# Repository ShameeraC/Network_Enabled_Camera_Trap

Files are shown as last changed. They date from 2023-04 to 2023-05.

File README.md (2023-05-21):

# Network-Enabled Camera Trap
This project deals with improving existing research equipment for ornithologists. One of the major concerns faced by researchers studying red-winged starlings at the University of Cape Town and its surrounding area, is that they are lacking the necessary funds and manpower to monitor their feeding and nesting behaviour. To address this issue, our team has decided to design a network-enabled camera trap.

The camera trap uses a PIR sensor to trigger a photo being taken. The photo is then saved to an  SD card, along with environmental data such as temperature and humidity measured by the camera trap's sensor. Afterwards, the camera trap uploads the saved image to Google Drive as well.

This repository details the design, testing, documentation and implementation of a network-enabled camera trap aimed at solving these problems completed by [Shameera Cassim](https://github.com/ShameeraC), [Thato Khoabane](https://github.com/kingtysen1969), [Litha Nohashe](https://github.com/lithanohasheUCT) and [Stefan Friedrich](https://github.com/stefanfriedric).

## File Structure
### Subsystems
This folder includes 4 subfolders - one for each submodule in the system. These are:
 * Camera System
    * By Stefan Friedrich
 * Image Transmission and Processing
    * By Shameera Cassim
 * Mounting and Housing
    * By Litha Nohashe
 * Power Management
    * By Thato Khaboane

### Documentation
Contains all relevant documentation for the project including project submissions.

### Interfacing
Contains all files relating to two or more subomdules.

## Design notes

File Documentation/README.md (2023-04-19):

# Network-Enabled Camera Trap/Documentation
Contains all relevant documentation for the project including project submissions.

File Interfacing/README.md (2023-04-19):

# Network-Enabled Camera Trap/Interfacing
Contains all files relating to two or more subomdules.

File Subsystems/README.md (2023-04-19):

# Network-Enabled Camera Trap/Subsystems
This folder includes 4 subfolders - one for each submodule in the system. These are:
Camera System;
Communication;
Mounting and Housing; and
Power Management.

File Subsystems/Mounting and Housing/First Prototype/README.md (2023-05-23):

This folder contains the design of the first prototype.

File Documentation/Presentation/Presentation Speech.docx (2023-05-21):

Intro & Problem Statement:

INTERESTING INTRO LINE

Good afternoon Dr. Paine, Dr. Schonken and the rest of the audience. Monitoring animals by hand is a long and tedious process. It often involves setting up camp in one spot with a hand-held camera and a notebook for several hours at a time. While nothing quite beats the thrill of capturing good data, a researcher’s presence in an animal’s habitat could disturb them or drive them away. Some animals, like birds, also build their nests in trees or on top of high buildings. This poses problems for the observer. An easy solution is obviously using a camera trap.

CLICK

The inspiration for this project comes from Dr Celiwe Ngcamphalala who studies red-winged starlings on UCT Upper Campus. Her research forms a part of the global change and urban birds research project at the FitzPatrick Institute. Red-Winged Starlings are known for thriving on UCTs campus, and the behaviour of these birds is studied by several ornithologists. Dr Ngcamphalala needs a low-cost solution for tracking the activity of red-winged starlings in their nests. This includes, among other things, how long it takes for their eggs to hatch and the birds’ feeding behavior.

In response, we have developed a low-cost network-enabled camera trap to be used by ornithologists at the FitzPatrick Institute. The final system is triggered by body heat and takes photos which are uploaded to Google Drive with environmental sensor data. These images are processed at a later stage.

CLICK

Housing:

Following the project taking a life of its own, resulting in a shift in focus, this system had to be adapted from a wild, remote outdoor area to a more urban and furnished environment. The assembly is made of two parts; one to house the camera and transmission circuitry, and one to house the power supplying system. The housing opens only to expose the sensors to the environment during operation, otherwise it is built enclosed.

Due to the narrow nature of the setting environment, the circuit boards and the housing were optimized to be compact in terms of size, but to also leave some space for mounting. It is recommended that the system be mounted with a variation of a chair angle bracket where it should rest on its longest side (resulting in a setting whereby it is longer horizontally). Because of its lightweight nature and simplicity, there is a lot of flexibility around how this may be achieved. This is ideal given that these birds build their nests in the most random places on campus. For ease of use, cable ties may be used to keep the system in place with respect to the bracket or alternatively, they may be joined using bolts, nuts and washers.

CLICK

Power:

The power subsystem has

CLICK

Camera:

The camera subsystem has both hardware and software components. Put together, it is able to capture a photo of an animal as it passes by. Not only does it do this, but it also captures environmental data such as temperature and humidity. The picture taken is then stored on an SD card, along with the environmental data, which is embedded in the image name.

To achieve this functionality, the ESP32-CAM was used. It is a low-cost microcontroller which features an on-board 2MP camera. It also consumes little power, especially in deep-sleep mode, making it ideal for longer deployments. An external trigger was used to wake the camera up and let it know that an animal is passing by. This trigger took the form of a Passive Infra-Red (PIR) sensor circuit, which registers a difference between the ambient temperature and the body heat of an animal.

The prototype circuit was built and tested. Overall, the picture quality is satisfactory, but the camera does sometimes take photos that have a greenish hue. This usually happens during the initialization of the camera and therefore only affects the first couple of photos. It could be prevented by increasing the shutter delay, but this comes at the risk of missed images. Otherwise, the PIR sensor works well up to 7m away from a target. Naturally, some false triggering still occurs but future iterations of the camera subsystem could include on-board image processing to remove these false triggers from the picture batch. As of right now, however, this is left to a separate submodule.

CLICK

Image Transmission and Processing:

The Image Transmission and Processing subsystem has two main functions. It uploads the images taken by the camera subsystem to a Google Drive folder and processes the files to extract relevant data. The purpose of this is to allow for real-time access to data and reduce demand on researchers to manually sort through captured data thus saving time and effort that could be better spent elsewhere.

The transmission part of this subsystem is executed using the ESP-32 microcontroller and 2 main software components. The onboard code connects the camera to the internet and uploads images to Google Drive. Currently the board connects to a mobile hotspot. Further development would include connecting to eduroam (as research is on campus) or adding an additional wifi access point so that a mobile hotspot is not needed.

The image processing part of the subsystem does 2 main things:

- It checks if there is a bird in each image and stores a list of the images that do contain birds; and
- It processes this list of file names which contain temperature, humidity, and heat index data from the camera subsystem.

The images and graphs shown on the slide above are generated by the image processing subsystem which circles what it recognizes as a bird and plots the relevant data. Due to time constraints, the images were not taken with the system but rather with a cell phone.

This is all done in a Google Colab notebook allowing for easy access to the Google Drive. This also means that no images need to be downloaded before processing. Only images containing birds are processed and the data retrieved is plotted. Future development would include a dashboard with access to the images that do have birds in them as well as plots and further analysis of the data. A better object detection model would also be developed to ensure that no photos are incorrectly excluded from processing and to identify whether a bird is a starling.

CLICK

Conclusion:

This project was driven by the need for better low-cost equipment in the field of ornithology and we hope that the system we have designed makes the data gathering process both easier and more effective. Together, the above-discussed submodules form a network-enabled camera trap that will allow an ornithologist to monitor birds activity in and around their nests at a low cost. The camera and transmission subsystem specifically, cost approximately R300 in components. This specific solution has been optimized and tailored to suit the needs of the red-wing starling project. However, it can be modified to fit into several contexts. While there is room for our system to grow, we are proud to say that the solution we have built is able to successfully capture, save and transmit both images and sensor data as shown in the following demonstration.

CLICK

SHOW VIDEO

CLICK

Monitoring birds in the hustle of activity surrounding the UCT campuses is no easy task. In completing this project, we hope to have made the process at least somewhat easier. Thank you!

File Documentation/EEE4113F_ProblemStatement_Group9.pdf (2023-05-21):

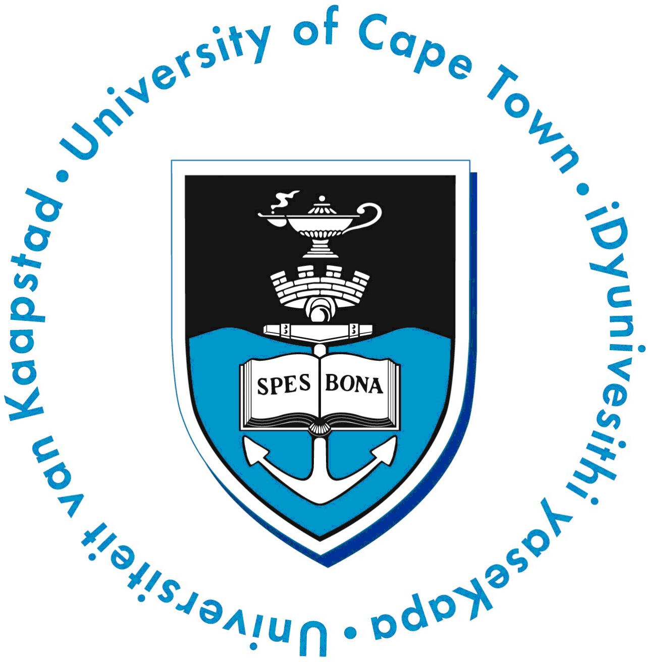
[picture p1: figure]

# EEE4113F: Problem Statement Group 9

Litha Nohashe (NHSLIT001)
Department of Electrical Engineering University of Cape Town
Cape Town, South Africa
nhslit001@myuct.ac.za

Stefan Friedrich (FRDSTE011) Department of Electrical Engineering University of Cape Town
Cape Town, South Africa
frdste011@myuct.ac.za

Shameera Cassim (CSSSHA020) Department of Electrical Engineering University of Cape Town
Cape Town, South Africa
csssha020@myuct.ac.za

Thato Khoabane (KHBTHA007) Department of Electrical Engineering University of Cape Town
Cape Town, South Africa
khbtha007@myuct.ac.za

## Context

We interviewed Kyle Walker who studies eagles in the Kalahari. One of his major concerns was that he is unable to confirm whether his camera traps are working once he has set them up in a tree. He also has no way of telling if the camera trap has moved from its set position. This means that if he forgets to turn the camera on, or something causes the camera to move in such a way that it is no longer facing the nest, he will not be able to capture the data that would have been recorded in that time.

## Problem Statement

Kyle, who monitors eagles in the Kalahari, needs a way to continuously monitor the equipment he uses because interestingly, in his world, he has to wait up to 8 months, for data retrieval, to confirm whether the equipment was working correctly.

1

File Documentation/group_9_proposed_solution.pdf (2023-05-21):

# EEE4113F: Proposed Solution

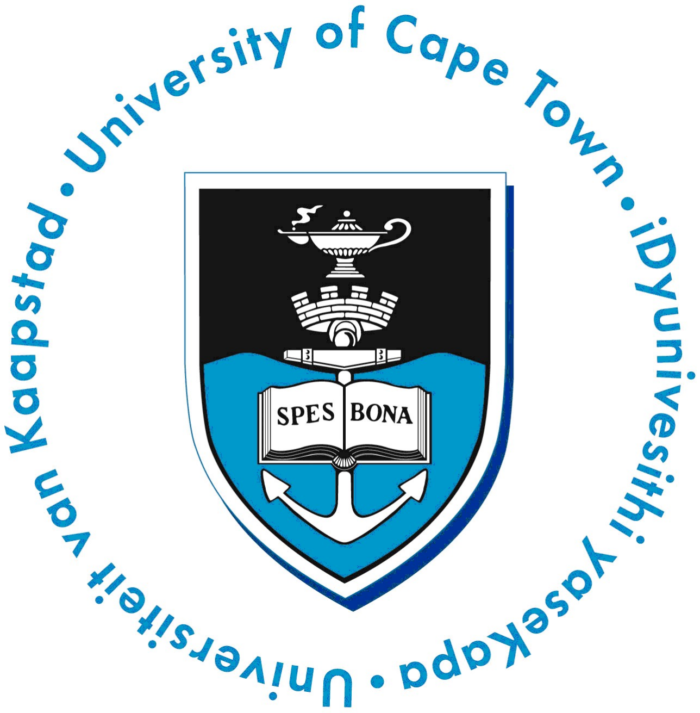
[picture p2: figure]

Prepared by:
Group 9:
Litha Nohashe (NHSLIT001), Stefan Friedrich (FRDSTE011), Shameera Cassim (CSSSHA020), Thato Khoabane (KHBTHA007)

Prepared for:
EEE4113F
Department of Electrical Engineering University of Cape Town

## Context

We interviewed Kyle Walker who studies eagles in the Kalahari. One of his major concerns was that he is unable to confirm whether his camera traps are working once he has set them up in a tree. He also has no way of telling if the camera trap has moved from its set position. This means that if he forgets to turn the camera on, or something causes the camera to move in such a way that it is no longer facing the nest, he will not be able to capture the data that would have been recorded in that time.

## Problem Statement

Kyle, who monitors eagles in the Kalahari, needs a way to remotely adjust his camera and access its status and contents, because interestingly, he has to wait up to 8 months, for data retrieval, to confirm that the equipment had been working correctly.

## Proposed Solution

In order to meet the requirements of our problem statement, we propose a system with the following 4 sub-modules:

1. Power Management,
2. Communications (transmissions),
3. Camera System (rotation and angle adjustment), and
4. Mounting, physical infrastructure and interfacing

The system will allow the camera trap’s position to be adjusted where necessary and wireless communications will be used to transmit images so that they can be accessed without physically retrieving the SD card currently used. In order to support these additional parts of the system, a power management sub-module is required - this would include the solar power currently used and configuring it for the additions to the system. Mounting and physical infrastructure is necessary to ensure that the system is secure and stable while interfacing is important to ensure the sub-modules are able to communicate and are compatible.

1

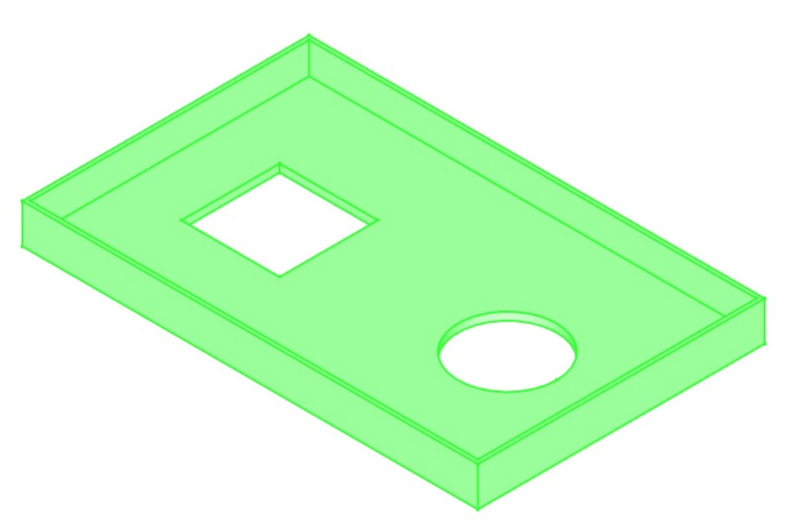
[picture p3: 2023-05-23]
Subsystems/Mounting and Housing/Final Design/FinalLid.png

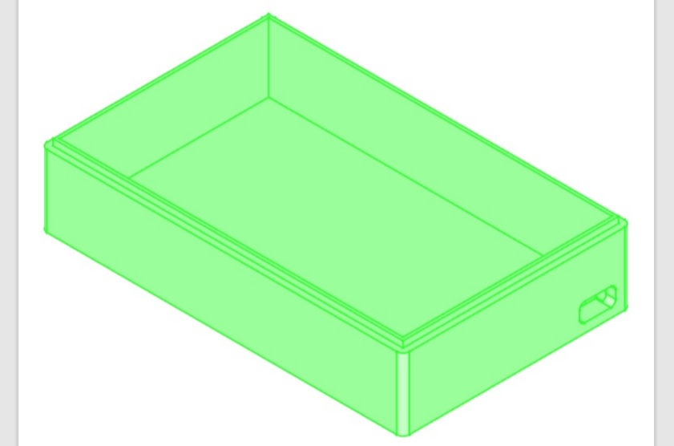
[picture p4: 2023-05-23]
Subsystems/Mounting and Housing/Final Design/FinalBody.png

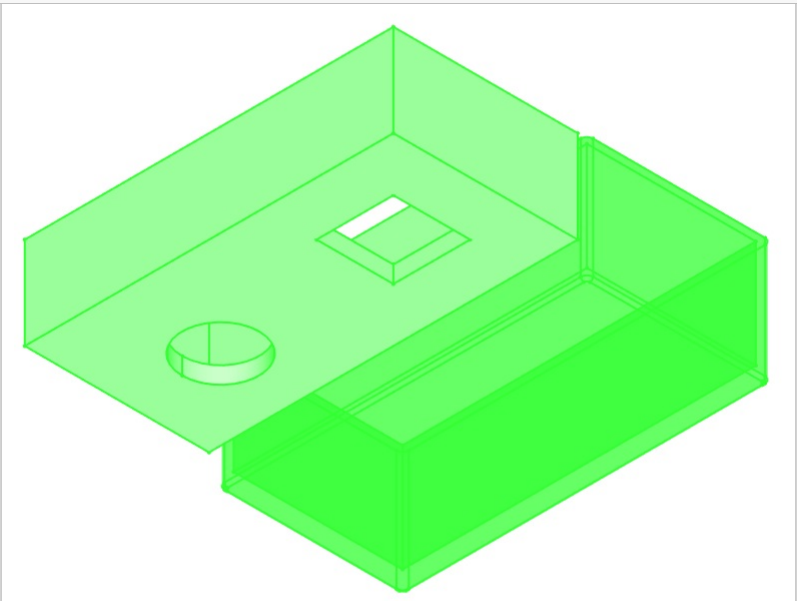
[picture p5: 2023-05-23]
Subsystems/Mounting and Housing/First Prototype/3D MODEL 2.png

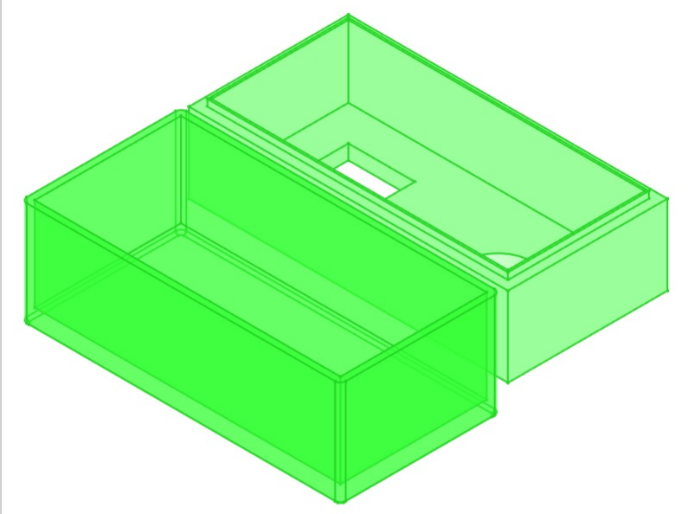
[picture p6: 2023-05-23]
Subsystems/Mounting and Housing/First Prototype/3D MODEL 1.png

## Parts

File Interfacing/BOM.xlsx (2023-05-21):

Group 9: Network Enabled Camera Trap
Bill of Materials
Item Number | Subsystem(s) | Item Name | Quantity | Unit Price | Total Price
1 | Camera & Transmission | ESP32-CAM: WIFI + BLUETOOTH CAMERA DEVELOPMENT BOARD | 1 | R 229.95 | R 229.95
2 | Camera | Passive Infra-Red (PIR) Sensor HC-SR501 | 1 | R 26.00 | R 26.00
3 | Camera | Temperature and Humidity Sensor DHT11 | 1 | R 33.91 | R 33.91
 |  |  |  |  | R 289.86

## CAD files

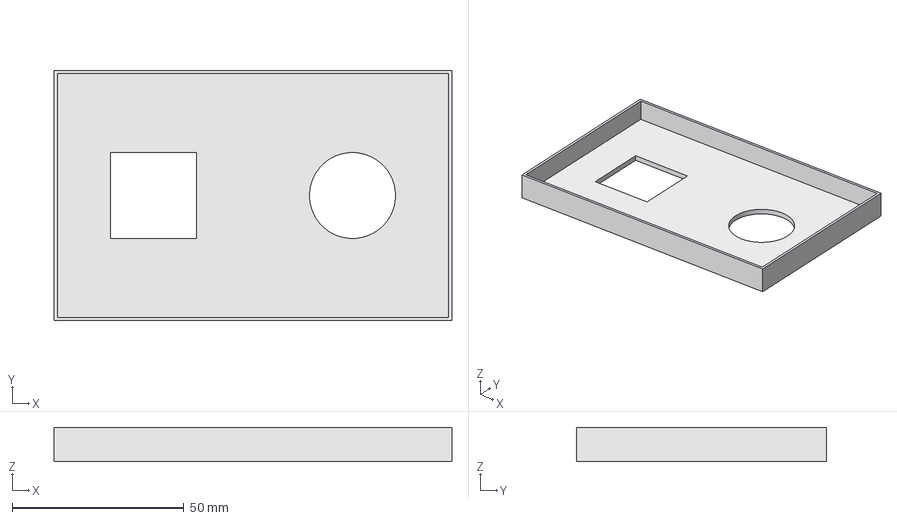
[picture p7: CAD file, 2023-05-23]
Subsystems/Mounting and Housing/Final Design/LIDV2.FCStd
116.0 x 73.0 x 10.0 mm

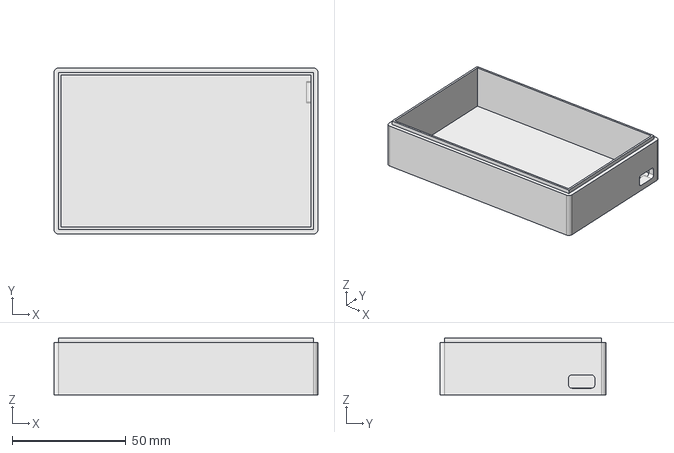
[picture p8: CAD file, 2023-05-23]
Subsystems/Mounting and Housing/Final Design/BASEV2.FCStd
116.0 x 73.0 x 25.0 mm

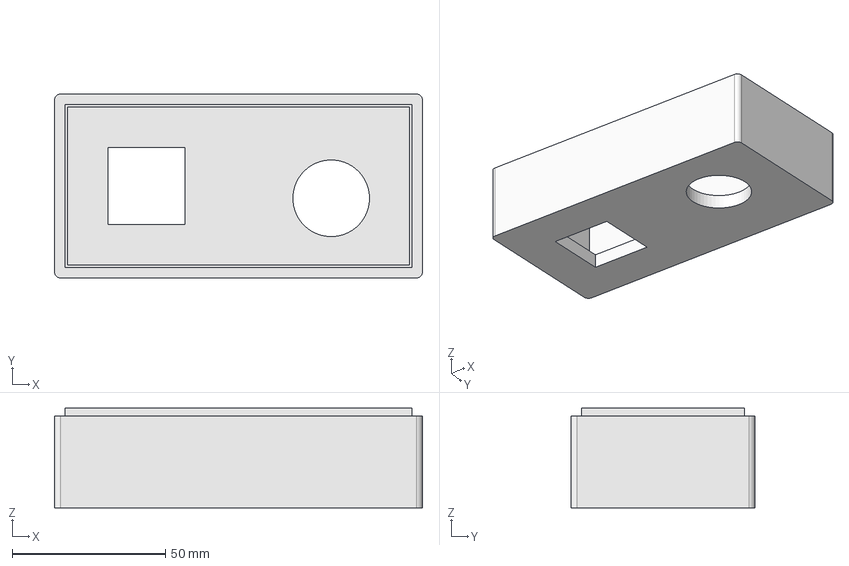
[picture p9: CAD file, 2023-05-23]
Subsystems/Mounting and Housing/First Prototype/BoxLid.FCStd
120.0 x 60.0 x 32.5 mm

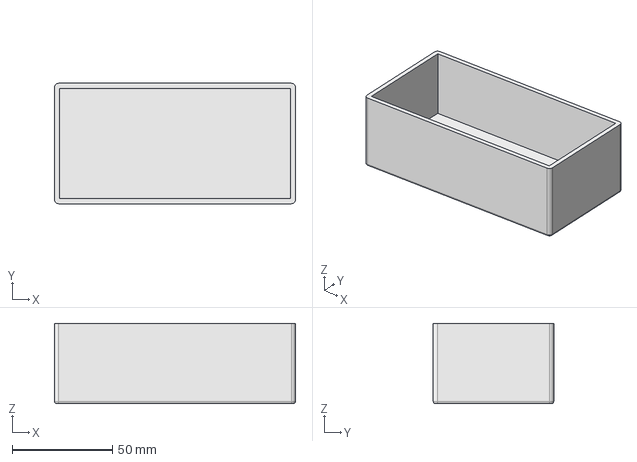
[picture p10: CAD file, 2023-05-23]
Subsystems/Mounting and Housing/First Prototype/BOX.FCStd
120.0 x 60.0 x 40.0 mm

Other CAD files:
Subsystems/Mounting and Housing/First Prototype/BOXASSEMBLY.FCStd

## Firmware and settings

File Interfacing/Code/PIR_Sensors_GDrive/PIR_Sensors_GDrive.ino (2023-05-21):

/*
  Stefan Friedrich and Shameera Cassim
  Camera Trap with SD card and Google Drive Functionality

  The scipt below contains code from the following online coding guides and tutorials:
  https://randomnerdtutorials.com/esp32-cam-pir-motion-detector-photo-capture/
  https://blog.pishop.co.za/how-to-take-photos-and-upload-it-to-google-drive-using-esp32-cam/

  Permission is hereby granted, free of charge, to any person obtaining a copy
  of this software and associated documentation files.
  The above copyright notice and this permission notice shall be included in all
  copies or substantial portions of the Software.
*/ 

#include <WiFi.h>
#include <WiFiClientSecure.h>
#include "soc/soc.h"
#include "soc/rtc_cntl_reg.h"
#include "Base64.h"

#include "Arduino.h"
#include "FS.h"                // SD Card ESP32
#include "SD_MMC.h"            // SD Card ESP32

#include "driver/rtc_io.h"
#include <EEPROM.h>            // read and write from flash memory
#include "DHT.h"
#include "esp_camera.h"

#define EEPROM_SIZE 1
#define DHTPIN 14
#define DHTTYPE DHT11
DHT dht(DHTPIN, DHTTYPE);

RTC_DATA_ATTR int bootCount = 0;

// Replace with your network credentials and your script deployment ID
const char* ssid     = "*******";
const char* password = "*******";
const char* myDomain = "script.google.com";
String myScript = "/macros/s/AKfycbwtS9wALNS8kEF1cMP7vp11rMfEVP7DPHptMQojy9lxJ4RYTJPeGJn3B4H9so6gmz28/exec"; 
String mimeType = "&mimetype=image/jpeg";
String myImage = "&data=";

int waitingTime = 30000; //Wait 30 seconds to google response.

#define PWDN_GPIO_NUM     32
#define RESET_GPIO_NUM    -1
#define XCLK_GPIO_NUM      0
#define SIOD_GPIO_NUM     26
#define SIOC_GPIO_NUM     27

#define Y9_GPIO_NUM       35
#define Y8_GPIO_NUM       34
#define Y7_GPIO_NUM       39
#define Y6_GPIO_NUM       36
#define Y5_GPIO_NUM       21
#define Y4_GPIO_NUM       19
#define Y3_GPIO_NUM       18
#define Y2_GPIO_NUM        5
#define VSYNC_GPIO_NUM    25
#define HREF_GPIO_NUM     23
#define PCLK_GPIO_NUM     22

int pictureNumber = 0;

void setup()
{
  WRITE_PERI_REG(RTC_CNTL_BROWN_OUT_REG, 0);
  
  Serial.begin(115200);
  delay(10);

  // start temperature and humidity sensor and read from it
  dht.begin();
  float h = dht.readHumidity();
  float t = dht.readTemperature();
  float hic = dht.computeHeatIndex(t, h, false);

  Serial.print(F("Humidity: "));
  Serial.print(h);
  Serial.print(F("%  Temperature: "));
  Serial.print(t);
  Serial.print(F("°C "));
  Serial.print(F("Heat Index: "));
  Serial.print(hic);
  Serial.print(F("°C \n"));

  Serial.setDebugOutput(true);

  camera_config_t config;
  config.ledc_channel = LEDC_CHANNEL_0;
  config.ledc_timer = LEDC_TIMER_0;
  config.pin_d0 = Y2_GPIO_NUM;
  config.pin_d1 = Y3_GPIO_NUM;
  config.pin_d2 = Y4_GPIO_NUM;
  config.pin_d3 = Y5_GPIO_NUM;
  config.pin_d4 = Y6_GPIO_NUM;
  config.pin_d5 = Y7_GPIO_NUM;
  config.pin_d6 = Y8_GPIO_NUM;
  config.pin_d7 = Y9_GPIO_NUM;
  config.pin_xclk = XCLK_GPIO_NUM;
  config.pin_pclk = PCLK_GPIO_NUM;
  config.pin_vsync = VSYNC_GPIO_NUM;
  config.pin_href = HREF_GPIO_NUM;
  config.pin_sscb_sda = SIOD_GPIO_NUM;
  config.pin_sscb_scl = SIOC_GPIO_NUM;
  config.pin_pwdn = PWDN_GPIO_NUM;
  config.pin_reset = RESET_GPIO_NUM;
  config.xclk_freq_hz = 20000000;
  config.pixel_format = PIXFORMAT_JPEG;
  config.frame_size = FRAMESIZE_VGA;  // UXGA|SXGA|XGA|SVGA|VGA|CIF|QVGA|HQVGA|QQVGA
  config.jpeg_quality = 10;
  config.fb_count = 1;
  
  esp_err_t err = esp_camera_init(&config);
  if (err != ESP_OK) {
    Serial.printf("Camera init failed with error 0x%x", err);
    return;
  }

  camera_fb_t * fb = NULL;
  fb = esp_camera_fb_get();  // take a photo and store its address in fb
  if(!fb) {
    Serial.println("Camera capture failed");
    delay(1000);
    ESP.restart();
    return;
  }

  Serial.println("Starting SD Card");
 
  delay(500);
  if(!SD_MMC.begin()){
    Serial.println("SD Card Mount Failed");
    //return;
  }
 
  uint8_t cardType = SD_MMC.cardType();
  if(cardType == CARD_NONE){
    Serial.println("No SD Card attached");
    return;
  }

  // initialize EEPROM with predefined size
  EEPROM.begin(EEPROM_SIZE);
  pictureNumber = EEPROM.read(0) + 1;
 
  // Path where new picture will be saved in SD Card
  String path = "/picture" + String(pictureNumber) +"_H"+h+"_T"+t+"_HIC"+hic+".jpg";
  String myFilename = "&filename=picture"+ String(pictureNumber) +"_H"+h+"_T"+t+"_HIC"+hic+".jpg";
 
  fs::FS &fs = SD_MMC;
  Serial.printf("Picture file name: %s\n", path.c_str());
 
  File file = fs.open(path.c_str(), FILE_WRITE);
  if(!file){
    Serial.println("Failed to open file in writing mode");
  }
  else {
    file.write(fb->buf, fb->len); // payload (image), payload length
    Serial.printf("Saved file to path: %s\n", path.c_str());
    EEPROM.write(0, pictureNumber);
    EEPROM.commit();
  }
  file.close();
  esp_camera_fb_return(fb); // return frame buffer for further use

  WiFi.mode(WIFI_STA);

  Serial.println("");
  Serial.print("Connecting to ");
  Serial.println(ssid);
  WiFi.begin(ssid, password);  

  while (WiFi.status() != WL_CONNECTED) {
    Serial.print(".");
    delay(500);
  }

  Serial.println("");
  Serial.println("STAIP address: ");
  Serial.println(WiFi.localIP());
    
  Serial.println("");

  Serial.println("Connect to " + String(myDomain));
  WiFiClientSecure client;
  client.setInsecure();
  
  if (client.connect(myDomain, 443)) {
    Serial.println("Connection successful");
  
    char *input = (char *)fb->buf;
    char output[base64_enc_len(3)];
    String imageFile = "";
    for (int i=0;i<fb->len;i++) {
      base64_encode(output, (input++), 3);
      if (i%3==0) imageFile += urlencode(String(output));
    }
    String Data = myFilename+mimeType+myImage;
    
    esp_camera_fb_return(fb);
    
    Serial.println("Send a captured image to Google Drive.");
    
    client.println("POST " + myScript + " HTTP/1.1");
    client.println("Host: " + String(myDomain));
    client.println("Content-Length: " + String(Data.length()+imageFile.length()));
    client.println("Content-Type: application/x-www-form-urlencoded");
    client.println();
    
    client.print(Data);
    int Index;
    for (Index = 0; Index < imageFile.length(); Index = Index+1000) {
      client.print(imageFile.substring(Index, Index+1000));
    }
    
    Serial.println("Waiting for response.");
    long int StartTime=millis();
    while (!client.available()) {
      Serial.print(".");
      delay(100);
      if ((StartTime+waitingTime) < millis()) {
        Serial.println();
        Serial.println("No response.");
        //If you have no response, maybe need a greater value of waitingTime
        break;
      }
    }
    Serial.println("\n");   
    while (client.available()) {
      Serial.print(char(client.read()));
    }  
  } else {         
    Serial.println("Connected to " + String(myDomain) + " failed.");
  }
  client.stop();

  esp_sleep_enable_ext0_wakeup(GPIO_NUM_13, 0); // PIR sensor is connecteed to pin 13
 
  Serial.println("Going to sleep now");
  delay(1000);
  esp_deep_sleep_start();
}

void loop() {

}

//https://github.com/zenmanenergy/ESP8266-Arduino-Examples/
String urlencode(String str)
{
    String encodedString="";
    char c;
    char code0;
    char code1;
    char code2;
    for (int i =0; i < str.length(); i++){
      c=str.charAt(i);
      if (c == ' '){
        encodedString+= '+';
      } else if (isalnum(c)){
        encodedString+=c;
      } else{
        code1=(c & 0xf)+'0';
        if ((c & 0xf) >9){
            code1=(c & 0xf) - 10 + 'A';
        }
        c=(c>>4)&0xf;
        code0=c+'0';
        if (c > 9){
            code0=c - 10 + 'A';
        }
        code2='\0';
        encodedString+='%';
        encodedString+=code0;
        encodedString+=code1;
        //encodedString+=code2;
      }
      yield();
    }
    return encodedString;
}

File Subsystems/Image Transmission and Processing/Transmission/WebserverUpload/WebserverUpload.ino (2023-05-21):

/*********
  
  This code was slightly altered for use on a network enabled camera trap developed for EEE4113F at UCT by Shameera Cassim

  It is based on the project completed by Rui Santos available at https://RandomNerdTutorials.com/esp32-cam-take-photo-display-web-server/

  **********/

  /********
  Rui Santos
  Complete project details at https://RandomNerdTutorials.com/esp32-cam-take-photo-display-web-server/
  
  IMPORTANT!!! 
   - Select Board "AI Thinker ESP32-CAM"
   - GPIO 0 must be connected to GND to upload a sketch
   - After connecting GPIO 0 to GND, press the ESP32-CAM on-board RESET button to put your board in flashing mode
  
  The above copyright notice and this permission notice shall be included in all
  copies or substantial portions of the Software.
*********/

#include "WiFi.h"
#include "esp_camera.h"
#include "esp_timer.h"
#include "img_converters.h"
#include "Arduino.h"
#include "soc/soc.h"           // Disable brownour problems
#include "soc/rtc_cntl_reg.h"  // Disable brownour problems
#include "driver/rtc_io.h"
#include <ESPAsyncWebServer.h>
#include <StringArray.h>
#include <SPIFFS.h>
#include <FS.h>

// Replace with your network credentials
const char* ssid = "******";
const char* password = "******";

// Create AsyncWebServer object on port 80
AsyncWebServer server(80);

boolean takeNewPhoto = false;

// Photo File Name to save in SPIFFS
#define FILE_PHOTO "/photo.jpg"
#define FILE_PHOTO2 "/photo2.jpg"

// OV2640 camera module pins (CAMERA_MODEL_AI_THINKER)
#define PWDN_GPIO_NUM     32
#define RESET_GPIO_NUM    -1
#define XCLK_GPIO_NUM      0
#define SIOD_GPIO_NUM     26
#define SIOC_GPIO_NUM     27
#define Y9_GPIO_NUM       35
#define Y8_GPIO_NUM       34
#define Y7_GPIO_NUM       39
#define Y6_GPIO_NUM       36
#define Y5_GPIO_NUM       21
#define Y4_GPIO_NUM       19
#define Y3_GPIO_NUM       18
#define Y2_GPIO_NUM        5
#define VSYNC_GPIO_NUM    25
#define HREF_GPIO_NUM     23
#define PCLK_GPIO_NUM     22

const char index_html[] PROGMEM = R"rawliteral(
<!DOCTYPE HTML><html>
<head>
  <meta name="viewport" content="width=device-width, initial-scale=1">
  <style>
    body { text-align:center; }
    .vert { margin-bottom: 10%; }
    .hori{ margin-bottom: 0%; }
  </style>
</head>
<body>
  <div id="container">
    <h2>ESP32-CAM Last Photo</h2>
    <p>It might take more than 5 seconds to capture a photo.</p>
    <p>
      <button onclick="rotatePhoto();">ROTATE</button>
      <button onclick="capturePhoto()">CAPTURE PHOTO</button>
      <button onclick="capturePhoto2()">CAPTURE PHOTO2</button>
      <button onclick="location.reload();">REFRESH PAGE</button>
    </p>
  </div>
  <div><img src="saved-photo" id="photo" width="70%"></div>
  <div><img src="saved-photo2" id="photo2" width="70%"></div>
</body>
<script>
  var deg = 0;
  function capturePhoto() {
    var xhr = new XMLHttpRequest();
    xhr.open('GET', "/capture", true);
    xhr.send();
  }
  function capturePhoto2() {
    var xhr = new XMLHttpRequest();
    xhr.open('GET', "/capture", true);
    xhr.send();
  }
  function rotatePhoto() {
    var img = document.getElementById("photo");
    deg += 90;
    if(isOdd(deg/90)){ document.getElementById("container").className = "vert"; }
    else{ document.getElementById("container").className = "hori"; }
    img.style.transform = "rotate(" + deg + "deg)";
  }
  function isOdd(n) { return Math.abs(n % 2) == 1; }
</script>
</html>)rawliteral";

void setup() {
  // Serial port for debugging purposes
  Serial.begin(115200);

  // Connect to Wi-Fi
  WiFi.begin(ssid, password);
  while (WiFi.status() != WL_CONNECTED) {
    delay(1000);
    Serial.println("Connecting to WiFi...");
  }
  if (!SPIFFS.begin(true)) {
    Serial.println("An Error has occurred while mounting SPIFFS");
    ESP.restart();
  }
  else {
    delay(500);
    Serial.println("SPIFFS mounted successfully");
  }

  // Print ESP32 Local IP Address
  Serial.print("IP Address: http://");
  Serial.println(WiFi.localIP());

  // Turn-off the 'brownout detector'
  WRITE_PERI_REG(RTC_CNTL_BROWN_OUT_REG, 0);

  // OV2640 camera module
  camera_config_t config;
  config.ledc_channel = LEDC_CHANNEL_0;
  config.ledc_timer = LEDC_TIMER_0;
  config.pin_d0 = Y2_GPIO_NUM;
  config.pin_d1 = Y3_GPIO_NUM;
  config.pin_d2 = Y4_GPIO_NUM;
  config.pin_d3 = Y5_GPIO_NUM;
  config.pin_d4 = Y6_GPIO_NUM;
  config.pin_d5 = Y7_GPIO_NUM;
  config.pin_d6 = Y8_GPIO_NUM;
  config.pin_d7 = Y9_GPIO_NUM;
  config.pin_xclk = XCLK_GPIO_NUM;
  config.pin_pclk = PCLK_GPIO_NUM;
  config.pin_vsync = VSYNC_GPIO_NUM;
  config.pin_href = HREF_GPIO_NUM;
  config.pin_sscb_sda = SIOD_GPIO_NUM;
  config.pin_sscb_scl = SIOC_GPIO_NUM;
  config.pin_pwdn = PWDN_GPIO_NUM;
  config.pin_reset = RESET_GPIO_NUM;
  config.xclk_freq_hz = 20000000;
  config.pixel_format = PIXFORMAT_JPEG;

  if (psramFound()) {
    config.frame_size = FRAMESIZE_UXGA;
    config.jpeg_quality = 10;
    config.fb_count = 2;
  } else {
    config.frame_size = FRAMESIZE_SVGA;
    config.jpeg_quality = 12;
    config.fb_count = 1;
  }
  // Camera init
  esp_err_t err = esp_camera_init(&config);
  if (err != ESP_OK) {
    Serial.printf("Camera init failed with error 0x%x", err);
    ESP.restart();
  }

  // Route for root / web page
  server.on("/", HTTP_GET, [](AsyncWebServerRequest * request) {
    request->send_P(200, "text/html", index_html);
  });

  server.on("/capture", HTTP_GET, [](AsyncWebServerRequest * request) {
    takeNewPhoto = true;
    request->send_P(200, "text/plain", "Taking Photo");
  });

  server.on("/saved-photo", HTTP_GET, [](AsyncWebServerRequest * request) {
    request->send(SPIFFS, FILE_PHOTO, "image/jpg", false);
  });
  server.on("/saved-photo2", HTTP_GET, [](AsyncWebServerRequest * request) {
    request->send(SPIFFS, FILE_PHOTO2, "image2/jpg", false);
  });

  // Start server
  server.begin();

}

void loop() {
  if (takeNewPhoto) {
    capturePhotoSaveSpiffs();
    takeNewPhoto = false;
  }
  delay(1);
}

// Check if photo capture was successful
bool checkPhoto( fs::FS &fs ) {
  File f_pic = fs.open( FILE_PHOTO );
  unsigned int pic_sz = f_pic.size();
  return ( pic_sz > 100 );
}
bool checkPhoto2( fs::FS &fs ) {
  File f_pic = fs.open( FILE_PHOTO2 );
  unsigned int pic_sz = f_pic.size();
  return ( pic_sz > 100 );
}
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

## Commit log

2023-04-28 comms webserver based on https://randomnerdtutorials.com/esp32-cam-take-photo-display-web-server/
2023-05-01 added PIR with sensors code
2023-05-01 combined camera and transmission v1
2023-05-12 Create esp32_cam_google_apps_scipt
2023-05-16 temporary updates to combined code for testing and added BOM
    [BOM.xlsx]
2023-05-18 Updated BOM for Camera System
    [BOM.xlsx]
2023-05-21 updated image transmission and processing
    [BOM.xlsx]
2023-05-23 Create README.md for First Prototype
